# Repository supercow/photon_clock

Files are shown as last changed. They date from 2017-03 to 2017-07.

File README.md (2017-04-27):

# Photon Clock

This repository contains all of the software and schematics required to build
and flash a 16x2 smart clock driven by a [Particle Photon](https://store.particle.io/#photon).

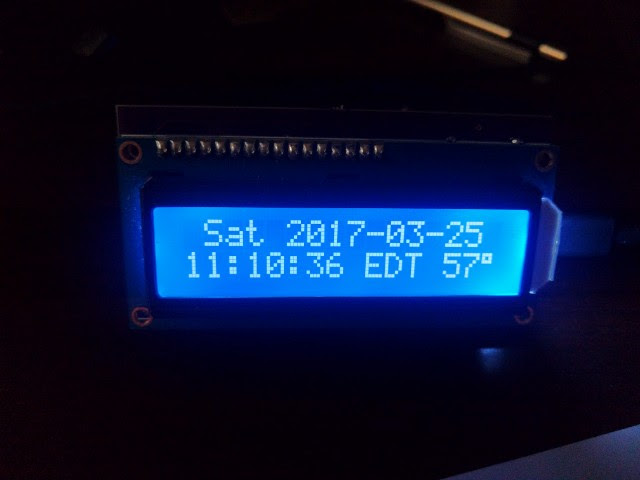
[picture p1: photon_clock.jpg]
Picture of completed clock


## Parts list

- PCB (see below for details)
- [HD44780 assembled LCD](https://www.adafruit.com/products/1447)
- Trim potentiometer (should come with the HD44780)
- [TMP36 temperature sensor](https://www.adafruit.com/products/165) (not needed if using external weather)
- [Particle Photon with headers](https://store.particle.io/#photon)
- ~50-60ohm THT resistor
- 10nF capacitor

### 3D printed enclosure
- Enclosure itself (see below for details)
- 4x M2x20mm machine screws
- 4x M2 nuts
- [Optional] 30mm cooling fan (requires fasteners and electrical tape)
- [Optional] Self-adhesive velcro strips

## PCB details

Eagle 8 format schematics are included in the "eagle" directory in this
repository. If you wish to order a PCB, you will need to use a service that
supports Eagle .brd files, or generate your own Gerbers.

I recommend [OSH Park](https://www.oshpark.com/) for ease of use, cost, quality,
and their cool purple soldermask. You can order this board directly with [this](https://www.oshpark.com/orders/cart)
link.

## 3D printed enclosure details

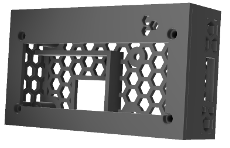
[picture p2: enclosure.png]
CAD rendering of 3D printed enclosure


Autodesk Fusion 360 source files and printable STL files are included in the "enclosure" directory in this repository.

### Assembly notes
* Print using 100% infill; no supports necessary.
* If using a cooling fan, cover the top of the partition that separates the Photon board from the temperature sensor with electrical tape. This will create a seal between the enclosure bottom and the PCB to block pushed air from impacting temperature readings. Fan is intended to be mounted externally using the mounting holes on the enclosure bottom.
* Enclosure is intended to be mounted under a computer monitor with velcro but works just fine unmounted. Velcro should be adhered to the enclosure side without the honeycomb cutouts.

## Building the software

### Pre-requisites

- A registered, Wi-Fi enabled Photon, ideally already connected
- The Particle IDE or command line tools installed and configured
- If you wish to use the command line version, a \*nix compatible shell is
  required

See instructions in the `code/build.sh` script to build and flash the Photon via
the command line. To flash via the Particle Atom IDE, open the project in `code`
and flash as usual.

If you wish to use the built-in temperature sensor, you will need to comment out
the following line:

`#define EXTERNAL_TEMP true`

## External integrations

In order for the clock to set the correct timezone, you will need to configure
the `timezone.json` external integration in the `integrations` directory in the
Particle console.

In order for the clock to collect external weather, you will need to configure
the `weather.json` external integration.

**Please note** that you must supply your own API key or none of the
integrations will work.

To configure each custom integration:
1. Go to [https://console.particle.io/integrations](https://console.particle.io/integrations) in your web browser
1. Click "NEW INTEGRATION"
1. Click "Webhook", then "Custom JSON"
1. Paste the contents of the relevant `.json` file from the `integrations`
   directory
1. Edit the URL section to include your API key
1. Click "CREATE WEBHOOK"

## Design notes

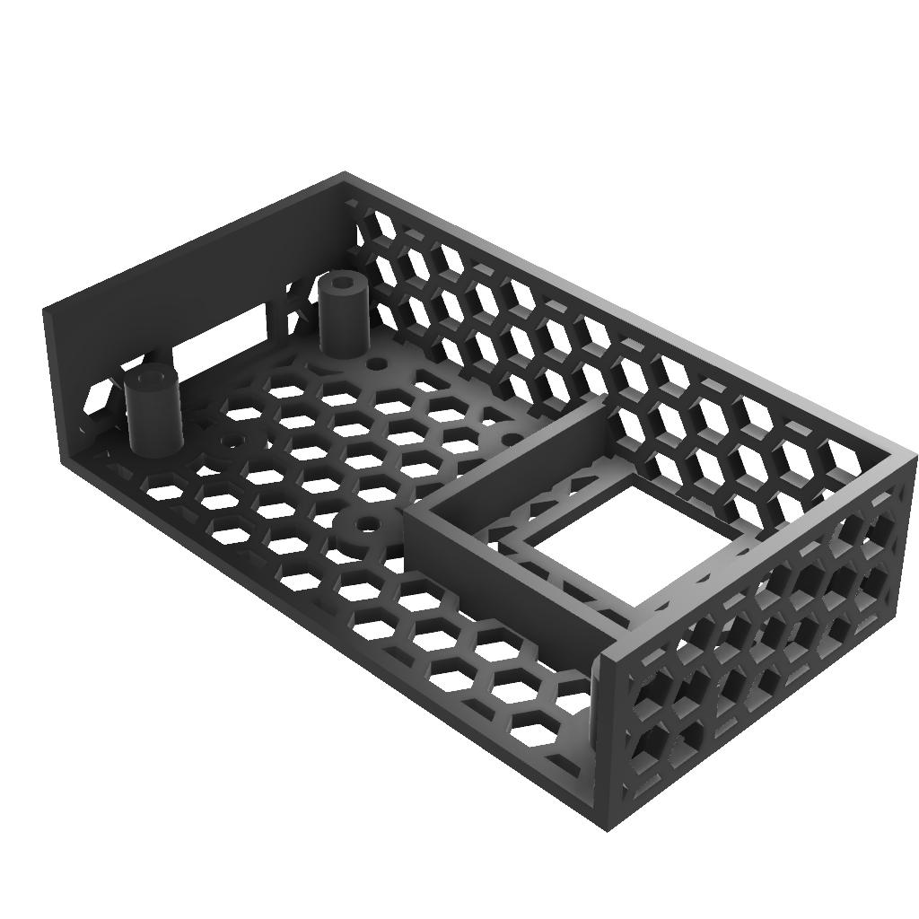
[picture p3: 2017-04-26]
enclosure/Renderings/enclosure-only_top-of-bottom.png

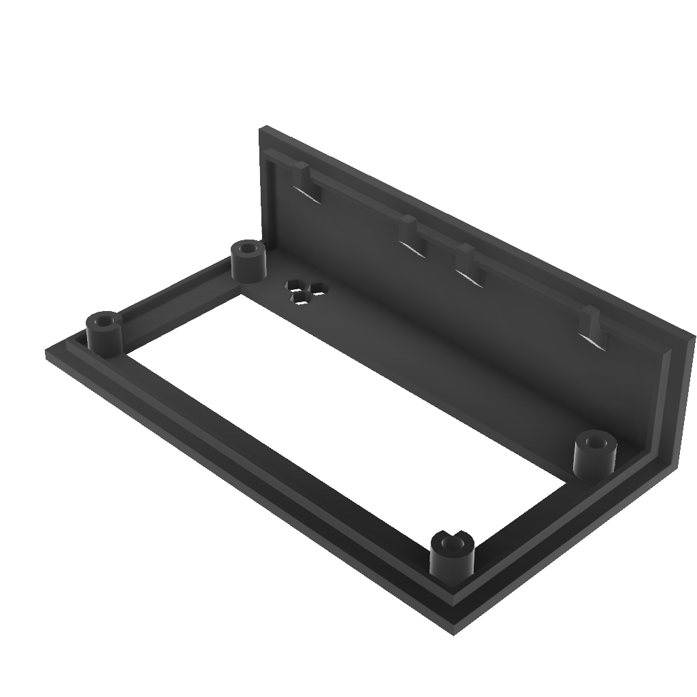
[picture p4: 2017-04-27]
enclosure/Renderings/enclosure-only_bottom-of-whole.png

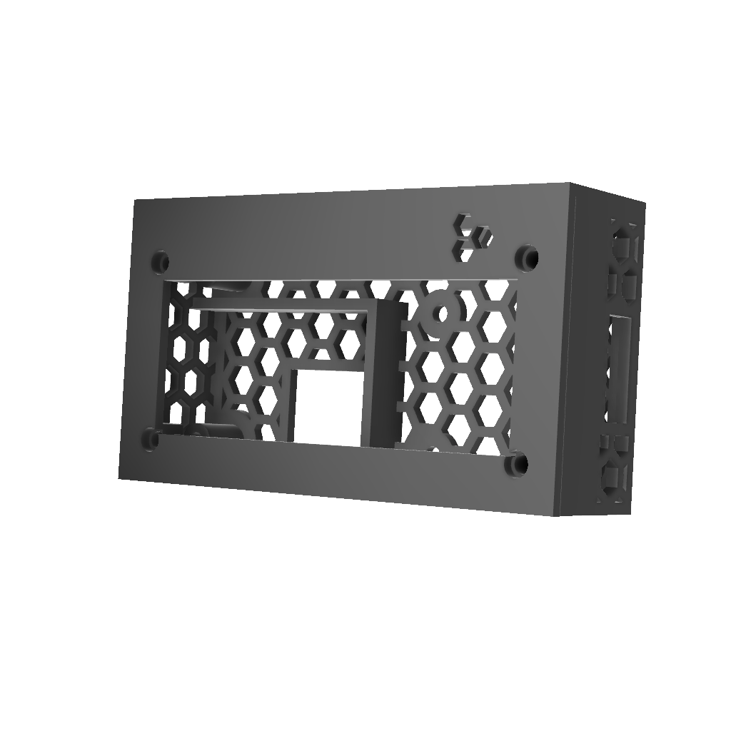
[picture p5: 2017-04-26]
enclosure/Renderings/enclosure-only_top-of-whole.png

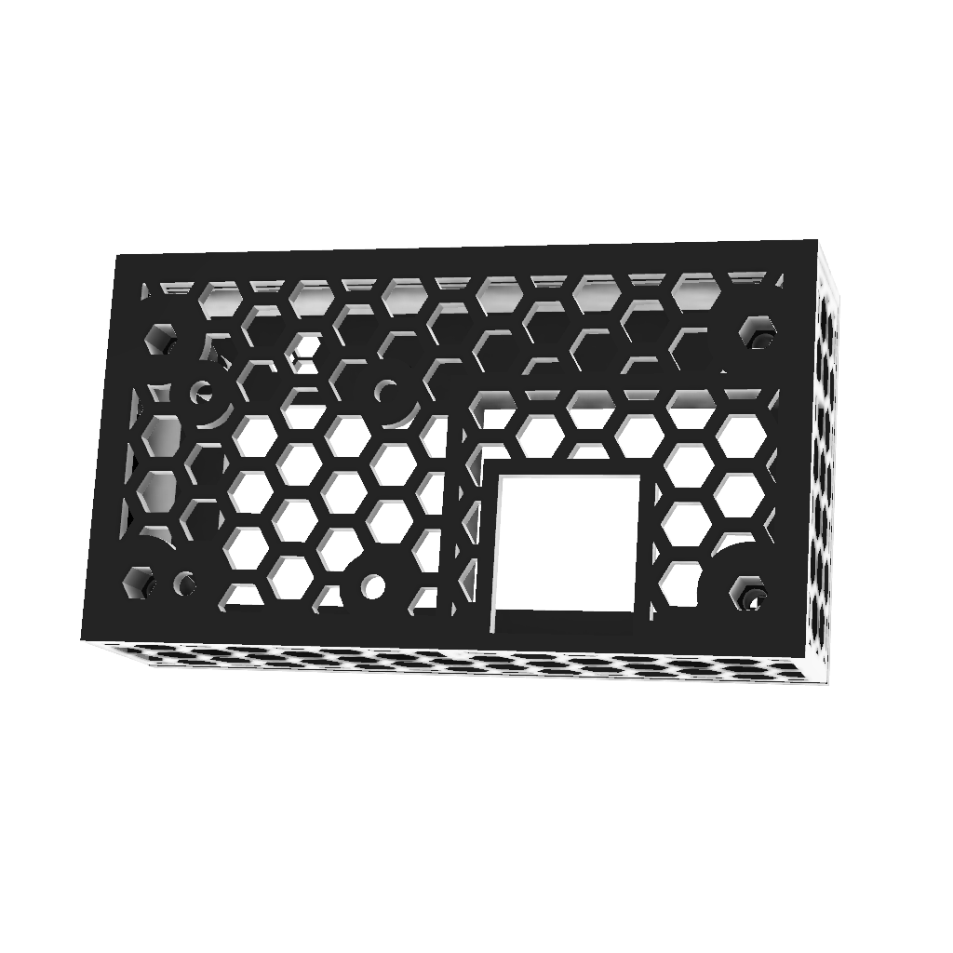
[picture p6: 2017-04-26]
enclosure/Renderings/enclosure-only_bottom-of-bottom.png

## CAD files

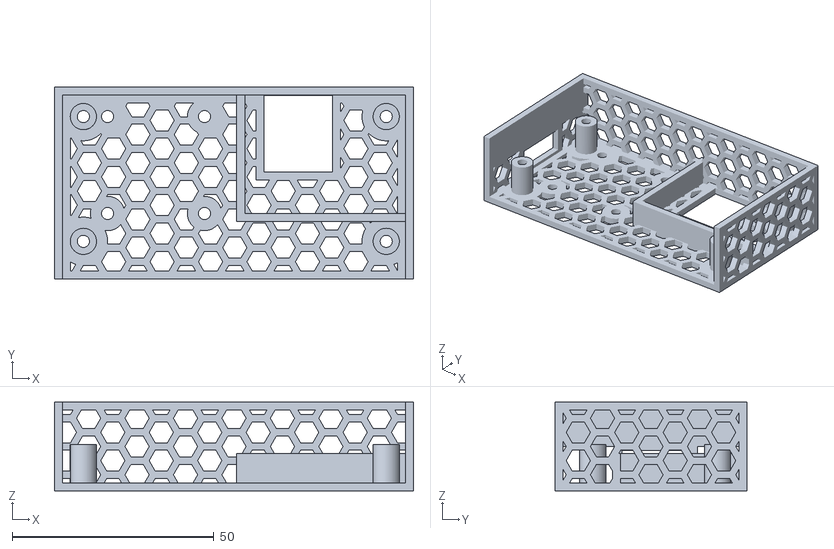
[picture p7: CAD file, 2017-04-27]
enclosure/Enclosure Bottom.stl
88.9 x 47.6 x 22.0

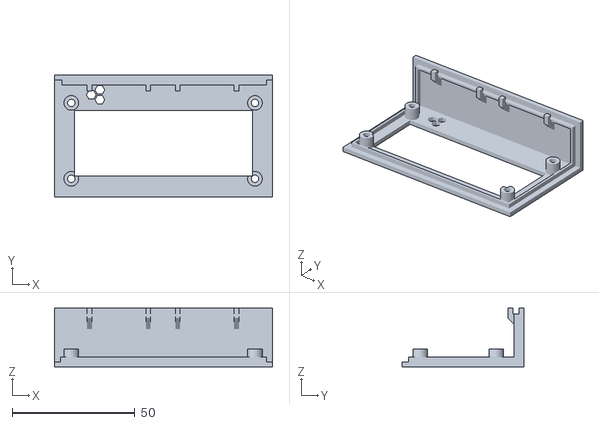
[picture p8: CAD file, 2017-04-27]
enclosure/Enclosure Top.stl
88.9 x 49.6 x 24.0

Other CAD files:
enclosure/Enclosure Bottom.f3d
enclosure/Enclosure Top.f3d

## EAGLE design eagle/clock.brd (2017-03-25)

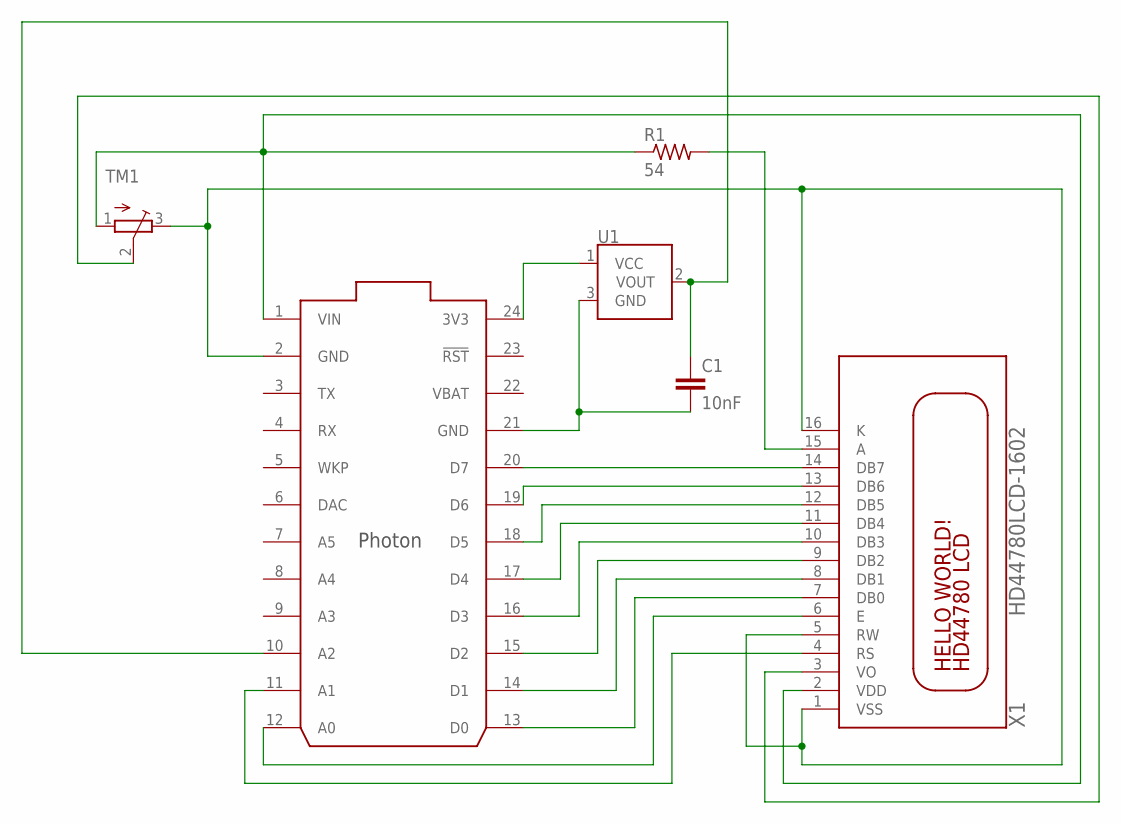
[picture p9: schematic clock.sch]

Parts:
C1: 10nF; CAP-PTH-10MM
R1: 54; 0309/12
TM1: TRIMPOT3386; TRIM-3386
U1: TMP36GT9; TO-92
U$1: PHOTON_WITH_HEADERS; PHOTON
X1: HD44780LCD-1602; LCD1602

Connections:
unnamed: U$1.19 (D6), X1.13 (DB6)
unnamed: C1.1, U1.2 (VOUT), U$1.10 (A2)
unnamed: U$1.12 (A0), X1.6 (E)
unnamed: U$1.18 (D5), X1.12 (DB5)
unnamed: U$1.17 (D4), X1.11 (DB4)
unnamed: U$1.20 (D7), X1.14 (DB7)
unnamed: U$1.16 (D3), X1.10 (DB3)
unnamed: U$1.15 (D2), X1.9 (DB2)
unnamed: U$1.14 (D1), X1.8 (DB1)
unnamed: U$1.13 (D0), X1.7 (DB0)
unnamed: U$1.11 (A1), X1.4 (RS)
unnamed: R1.2, X1.15 (A)
unnamed: TM1.2 (S), X1.3 (VO)
unnamed: U1.1 (VCC), U$1.24 (3V3)
unnamed: C1.2, U1.3 (GND), U$1.21 (GND)
VBAT: U$1.22 (VBAT)
VDD: R1.1, TM1.1 (A), U$1.1 (VIN), X1.2 (VDD)
VSS: TM1.3 (E), U$1.2 (GND), X1.1 (VSS), X1.5 (RW), X1.16 (K)

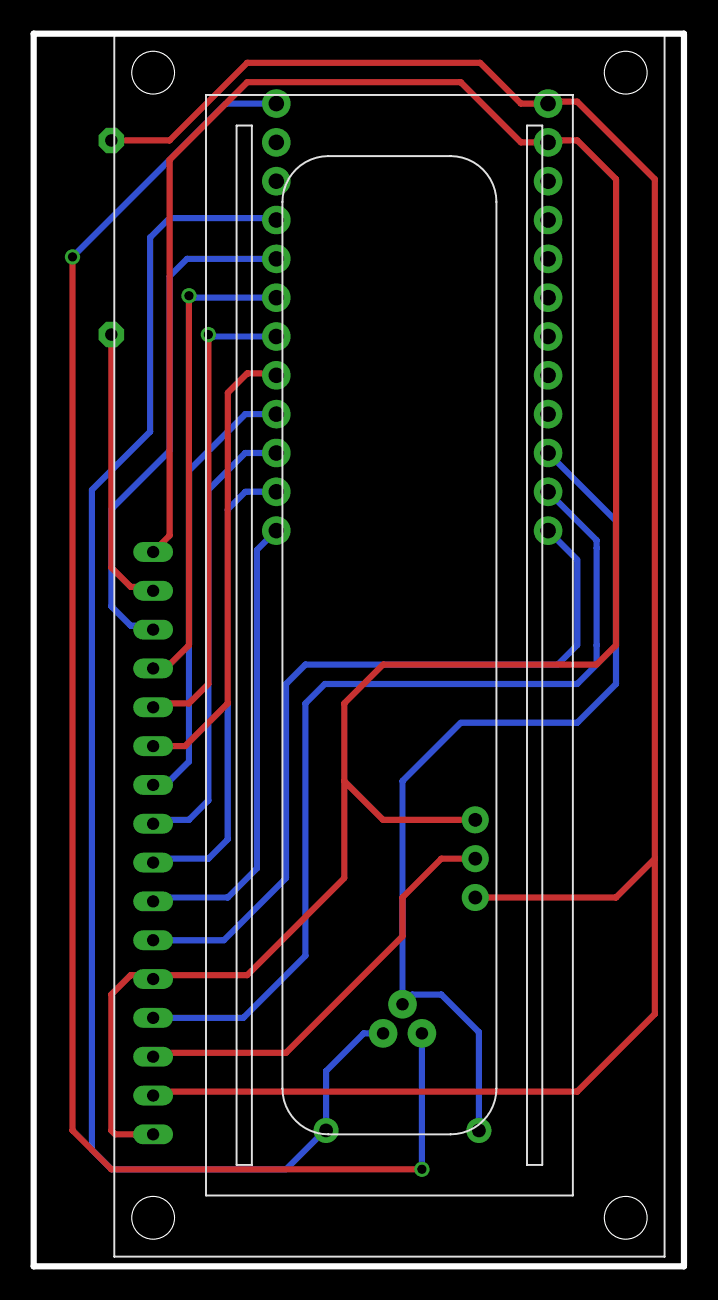
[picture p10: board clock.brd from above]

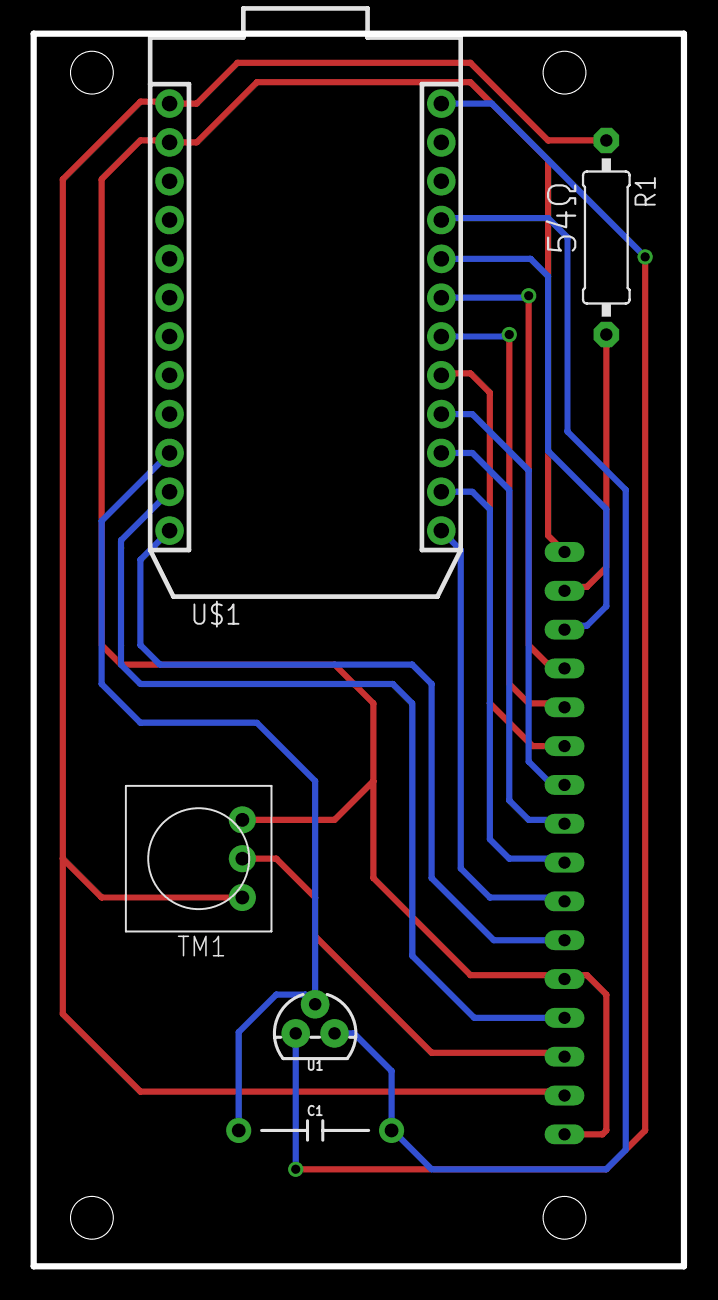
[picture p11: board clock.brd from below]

Board: 2 copper layers, 42.5 x 80.6 mm, 6 parts (5 on the bottom side), 17 nets.

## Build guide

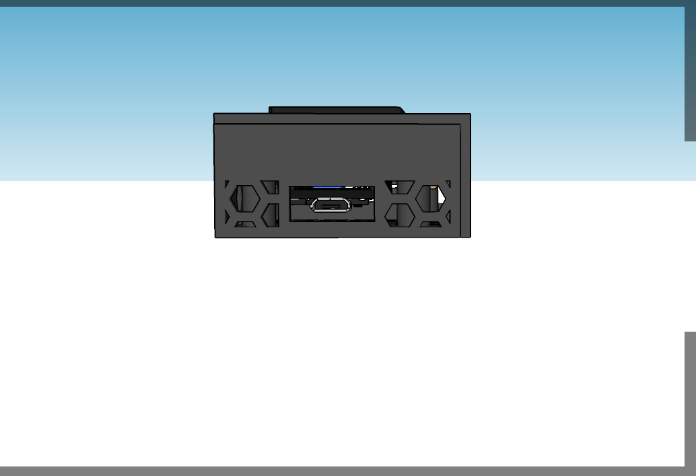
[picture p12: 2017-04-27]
enclosure/Renderings/assembled_side-usb.png

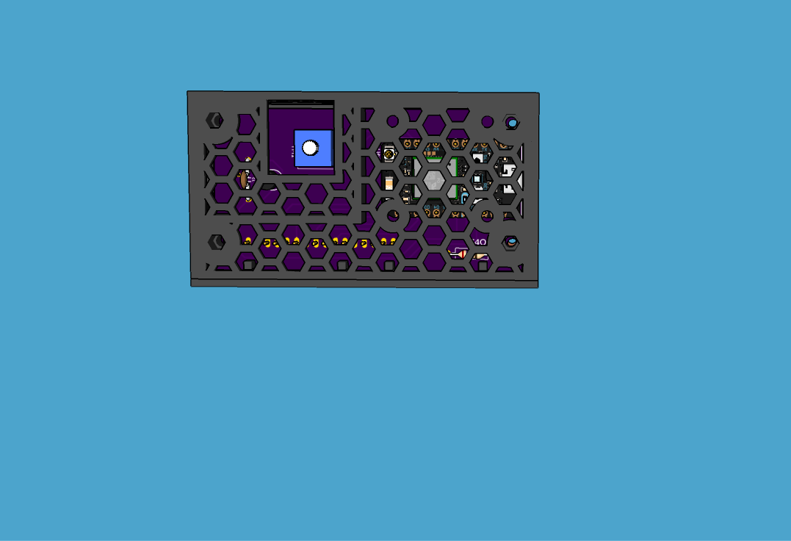
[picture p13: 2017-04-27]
enclosure/Renderings/assembled_bottom.png

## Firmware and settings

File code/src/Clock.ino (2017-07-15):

/*
 * Project Clock
 * Description:
 * Author:
 * Date:
 */

#include "application.h"
#include "LiquidCrystal/LiquidCrystal.h"

//LiquidCrystal lcd(A1, A0, D4, D5, D6, D7, D0, D1, D2, D3);
LiquidCrystal lcd(A1, A0, D4, D5, D6, D7);

// Sync every 3 hours
#define SYNC_INTERVAL (60 * 60 * 1000 * 3)
#define WEATHER_SYNC_INTERVAL (60 * 1000 * 30)
#define EXTERNAL_TEMP true //uncomment to use weather API instead of onboard thermometer

#define STATE_WAITING 0
#define STATE_PUBLISHED 1
#define STATE_RECEIVED 2
#define STATE_SYNC_WAIT 3
#define STATE_SYNC_COMPLETE 4

int ts_state = STATE_WAITING;
int offset = -5;
String tzName = "EST";

int tempPin = A2;
double temp = 0.0;
double tempF = 0.0;
int tempVoltage = 0;

String weather = "???";
int weather_state = STATE_WAITING;
unsigned long lastWeatherUpdate = 0;

void weatherHandler(const char *event, const char *data) {
  float fWeather = atoi(data);
  fWeather += 0.5;
  int iWeather = fWeather;
  weather = iWeather;
  weather_state = STATE_RECEIVED;
}

void updateWeather() {
  String data = "";
  switch (weather_state) {
    case STATE_WAITING:
      Serial.println("Sent timezone request.");
      Particle.publish("weather", data, PRIVATE);
      weather_state = STATE_PUBLISHED;
      break;
    case STATE_PUBLISHED:
      // handler changes state to STATE_RECEIVED, do nothing here
      Serial.println("Waiting for weather API hook...");
      break;
    case STATE_RECEIVED:
      Serial.println("Received updated weather.");
      weather_state = STATE_WAITING;
      lastWeatherUpdate = millis();
      break;
  }
}

void timezoneHandler(const char *event, const char *data) {

  char* token = strtok(strdup(data)," ");
  offset = (atoi(token) / 3600);
  token = strtok(NULL, " ");
  tzName = token;

  ts_state = STATE_RECEIVED;
  Serial.print("Set offset to ");
  Serial.println(offset, DEC);

  Serial.println("Set tzName to " + tzName);
}

void syncTime() {
  String data = "";
  switch (ts_state) {
    case STATE_WAITING:
      Serial.println("Sent timezone request.");
      Particle.publish("timezone", data, PRIVATE);
      ts_state = STATE_PUBLISHED;
      break;
    case STATE_PUBLISHED:
      // handler changes state to STATE_RECEIVED, do nothing here
      Serial.println("Waiting for timezone API hook...");
      break;
    case STATE_RECEIVED:
      Serial.println("Received time zone, requesting sync.");
      //Time.zone(offset);
      Particle.syncTime();
      ts_state = STATE_SYNC_WAIT;
      break;
    case STATE_SYNC_WAIT:
      if (Particle.syncTimePending()) {
	Serial.println("Waiting for Particle sync");
      } else {
        Serial.println("Received sync from Particle");
        ts_state = STATE_SYNC_COMPLETE;
      }
      break;
    case STATE_SYNC_COMPLETE:
      ts_state = STATE_WAITING;
      Serial.println("Synchronized time to " + Time.format(Time.now(), TIME_FORMAT_ISO8601_FULL));
      delay(250);
      break;
  }
}

// setup() runs once, when the device is first turned on.
void setup() {
  Serial.begin(9600);
  lcd.clear();
  lcd.begin(16,2);
  lcd.print("Initializing...");
  syncTime();

  pinMode(tempPin, INPUT);
  Particle.variable("tempVoltage", &tempVoltage, INT);
  Particle.variable("temp", &temp, DOUBLE);
  Particle.variable("tempF", &tempF, DOUBLE);
  Particle.variable("weather", &weather, STRING);

  Particle.subscribe("hook-response/timezone",timezoneHandler,MY_DEVICES);
  Particle.subscribe("hook-response/weather",weatherHandler,MY_DEVICES);

}

// loop() runs over and over again, as quickly as it can execute.
void loop() {
  unsigned long lastSync = Particle.timeSyncedLast();
  if(millis() - lastSync > SYNC_INTERVAL) {
    Serial.println("Last sync " + Time.format(lastSync, TIME_FORMAT_ISO8601_FULL));
    syncTime();
  }

  if(lastSync == 0) {
    lcd.setCursor(0,0);
    lcd.print("Syncing time...");
    lcd.setCursor(0,1);
    lcd.print("                ");
    return;
  }

#ifndef EXTERNAL_TEMP
  tempVoltage = analogRead(tempPin);
  temp = (((tempVoltage * 3.3)/4095) - 0.5) * 100;
  tempF = ((temp * 9.0) / 5.0) + 32.0;
  String strTemp = (String)((int)tempF);
#else
  if ((millis() - lastWeatherUpdate > WEATHER_SYNC_INTERVAL) || lastWeatherUpdate == 0) {
    if ( (millis() -  lastWeatherUpdate > WEATHER_SYNC_INTERVAL * 4) && lastWeatherUpdate != 0 ){
      System.reset();
    } else {
      updateWeather();
    }
  }
  String strTemp = weather;
#endif

  Time.zone(offset);
  int currentTime = Time.now();
  String strDOW = Time.format(currentTime,"%a");
  String strDate = Time.format(currentTime, "%Y-%m-%d");
  String strTime = Time.format(currentTime, "%H:%M:%S");

  lcd.setCursor(0,0);
  lcd.print(" " + strDOW + " " + strDate + "  ");
  lcd.setCursor(0,1);
  lcd.print(strTime + " " + tzName + " " + strTemp + (char)223);
  delay(100);
}

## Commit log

2017-03-19 trying and failing to get timezone sync working
    [Clock.ino]
2017-03-25 Add eagle files
    [clock.brd, clock.sch]
2017-04-26 Added 3D printed enclosure and updated readme.
    [Enclosure Bottom.f3d, Enclosure Bottom.stl, Enclosure Top.f3d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]
2017-04-26 Fixed number of screws in readme.
2017-04-26 Updated model orientation to allow for printing without supports.
    [Enclosure Bottom.stl, Enclosure Top.stl]
2017-04-27 Updated readme w/ velcro notes; added new renderings of assembled unit (minus screws).

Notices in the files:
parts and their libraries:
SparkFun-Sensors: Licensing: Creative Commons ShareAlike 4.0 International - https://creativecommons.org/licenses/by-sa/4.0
